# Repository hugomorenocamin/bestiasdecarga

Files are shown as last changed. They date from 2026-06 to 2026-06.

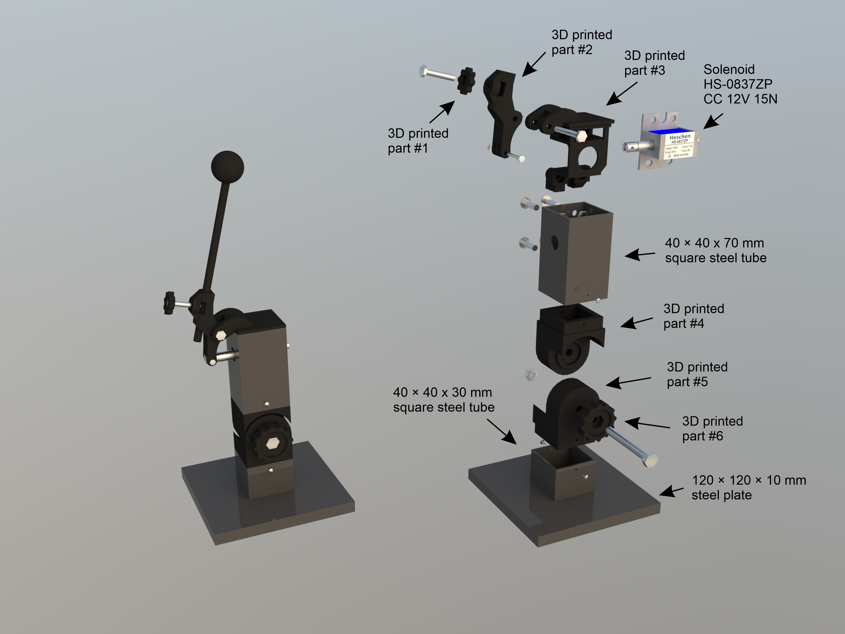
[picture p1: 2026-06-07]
SOLENOID-DRIVEN MALLET/Assembly drawing.jpg

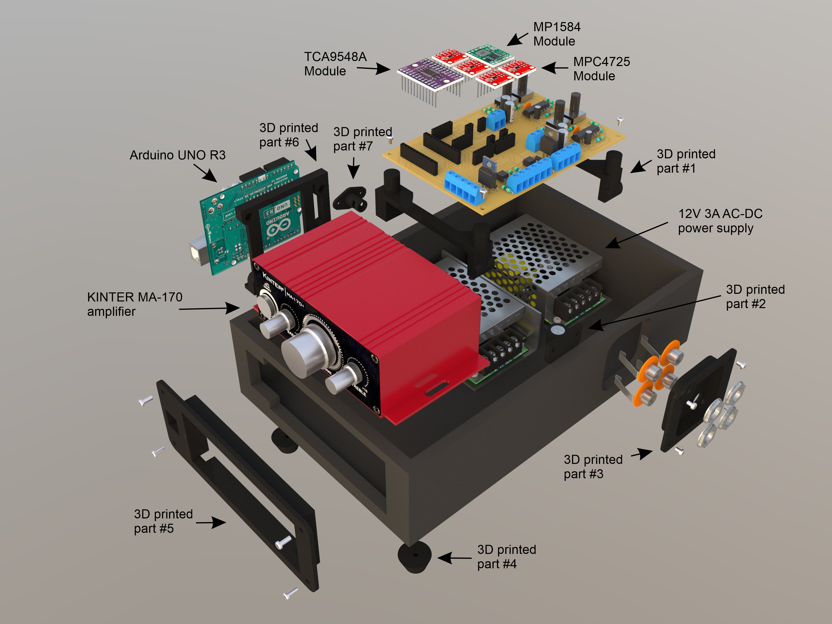
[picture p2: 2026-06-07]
RECEIVER/Assembly 3D drawing2.jpg

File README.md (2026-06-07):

# Bestias de carga
## Overview

This project is an artistic system that sonifies respiratory and cardiac signals in real time.
It operates as a critical reflection on labour, self-exploitation, and the physiological dimension of contemporary neoliberal production regimes.

The body is treated here not as metaphor, but as an operational site of measurement, extraction, and feedback.

The system translates physiological signals into sound, generating a direct physical representation of internal bodily rhythms under stress, attention, and exertion.

## System Structure

### The installation is composed of four interconnected physical modules:

- Part 01 – emitter

- Part 02 – receiver

- Part 03 – respiration belt

- Part 04 – solenoid-driven mallet

### Each module contains:

- Mechanical design and structural drawings

- 3D printable components (.stl)

- Electronics schematics and PCB design

- Firmware (Arduino-based control system)

## Artistic Intent

This work operates at the intersection of bio-sensing and sound art.

It questions:

- the quantification of the body under self-optimization logics

- the feedback loops between attention, labour, and exhaustion

The system is not a medical device, nor a fitness product. It is an artistic instrument.

## Use & Reproduction

This project is released for:

- study and research

- educational use

- artistic reproduction and reinterpretation

- exhibition in cultural, academic and artistic contexts

It is not intended for commercial exploitation.

See ARTISTIC_USE_POLICY.md for detailed terms.

[Artistic Use Policy](ARTISTIC_USE_POLICY.md)

## License

All files in this repository are licensed under:

Creative Commons Attribution-NonCommercial-ShareAlike 4.0 International (CC BY-NC-SA 4.0)

See LICENSE for full terms.

## Author

Hugo Moreno Camín

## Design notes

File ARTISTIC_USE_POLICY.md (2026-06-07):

# Artistic Use Policy

This document clarifies the intended use of this project beyond the legal text of its license.

## Intent

This project is an open artistic system designed for reproduction, study, and reinterpretation within artistic and academic contexts.

It is not intended to function as a commercial product, kit, or manufacturable device.

## Permitted Uses

- Non-commercial reproduction of the system

- Educational and research use

- Artistic modification and derivative works

- Exhibition of derived works in cultural, artistic, and academic contexts

## Not Permitted Without Explicit Permission

- Commercial manufacturing or industrial reproduction of the device

- Sale of assembled units

- Sale of kits or partial kits

- Sale of design files (STL, PCB, schematics, firmware)

- Use of the design as a commercial product or embedded component in a product

## On Derivative Works

Artistic reinterpretations are encouraged.

However, derivative works must:

- Be conceptually and materially distinct from the original system as a device

- Maintain attribution to the original author

- Be released under the same license terms when distributed

## Contact for Artistic Use

If you intend to use any part of this project in an artistic context that involves public exhibition, commissioning, or institutional support, please contact the author in advance to clarify terms and attribution:

Email: hugomoreno311@gmail.com

This allows us to ensure proper attribution and discuss appropriate conditions of use within artistic and curatorial contexts.

## Closing Statement

This project understands the body as a site of measurement, labour, and extraction.

Its openness is intended as a critical gesture, not as a pathway to commodification.

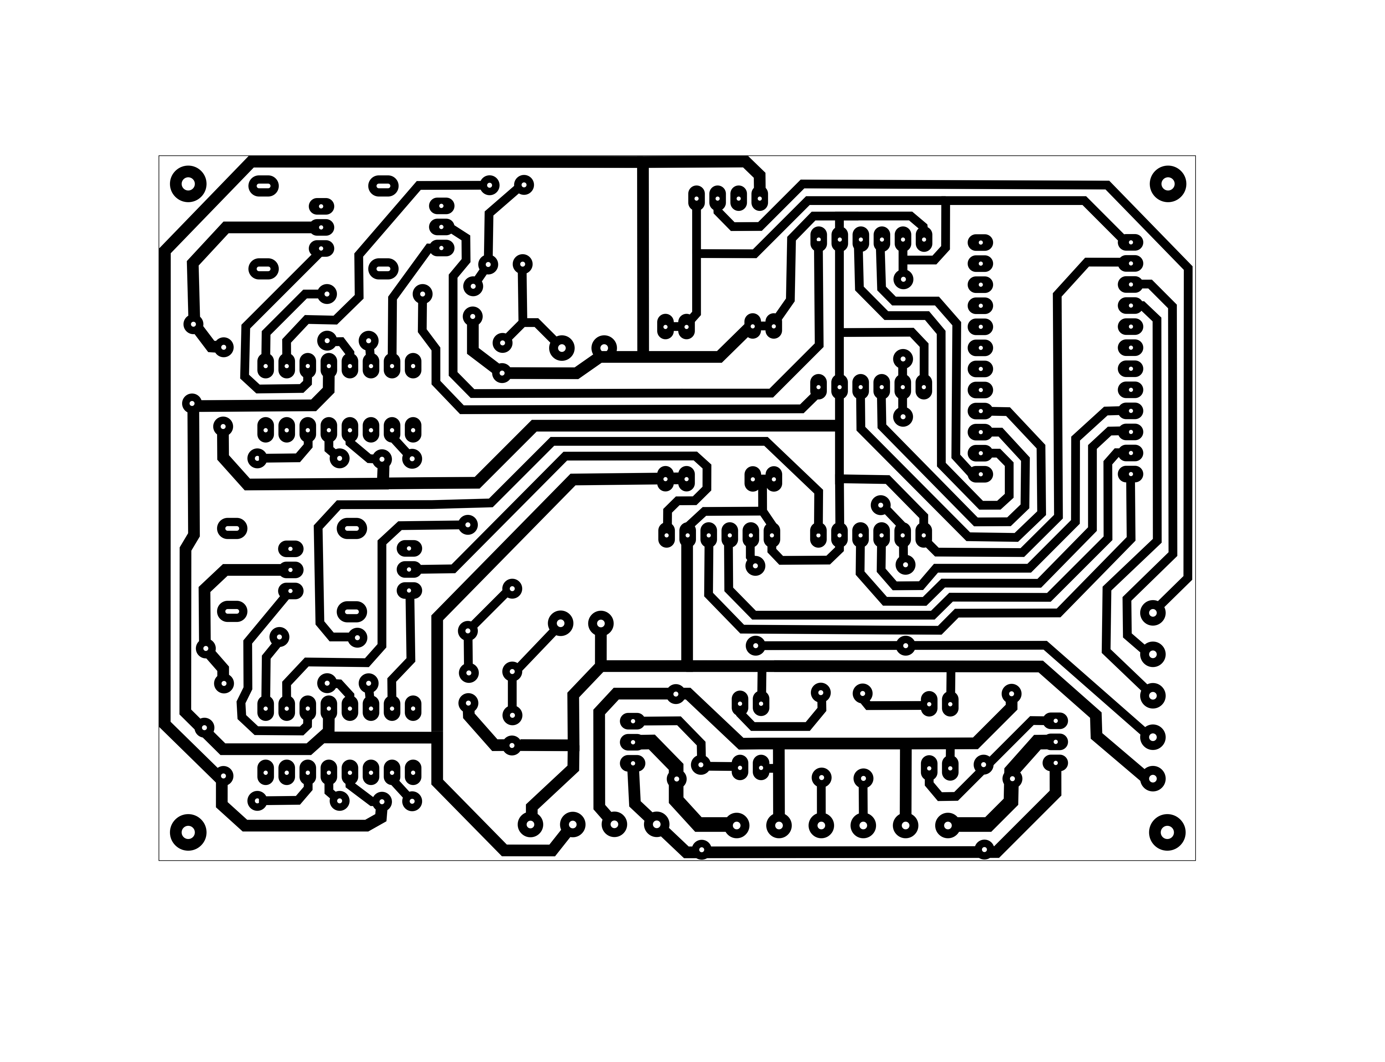
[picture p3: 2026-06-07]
RECEIVER/ELECTRONICS/PCB layout.jpg

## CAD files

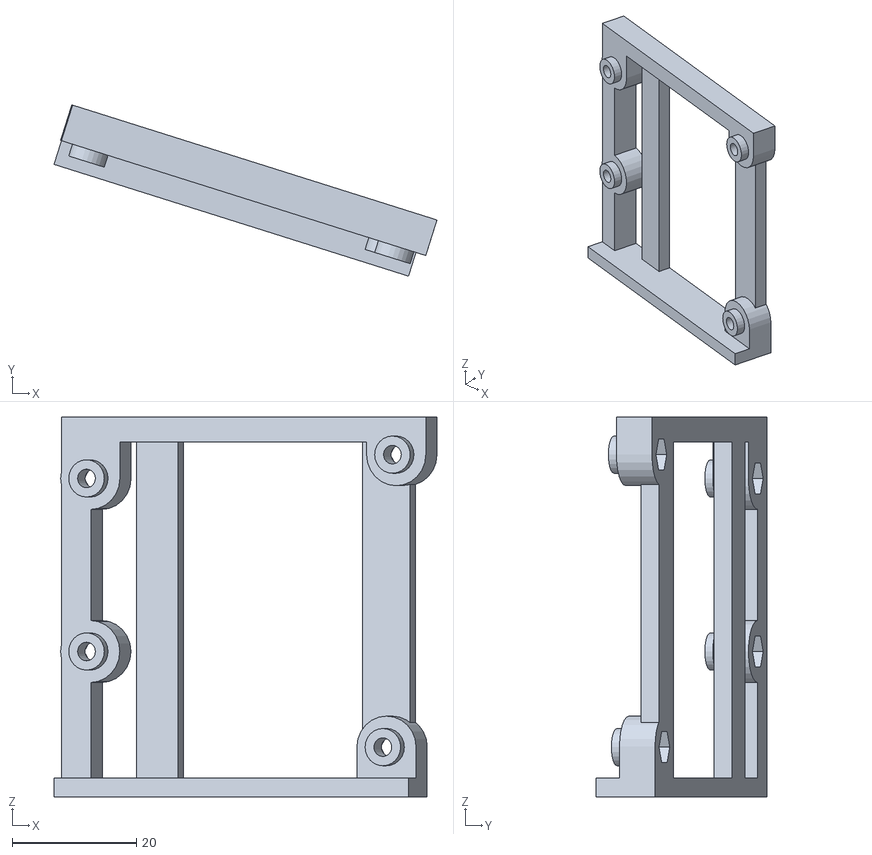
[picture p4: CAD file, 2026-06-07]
RECEIVER/STL/part#6.stl
61.7 x 27.6 x 61.1

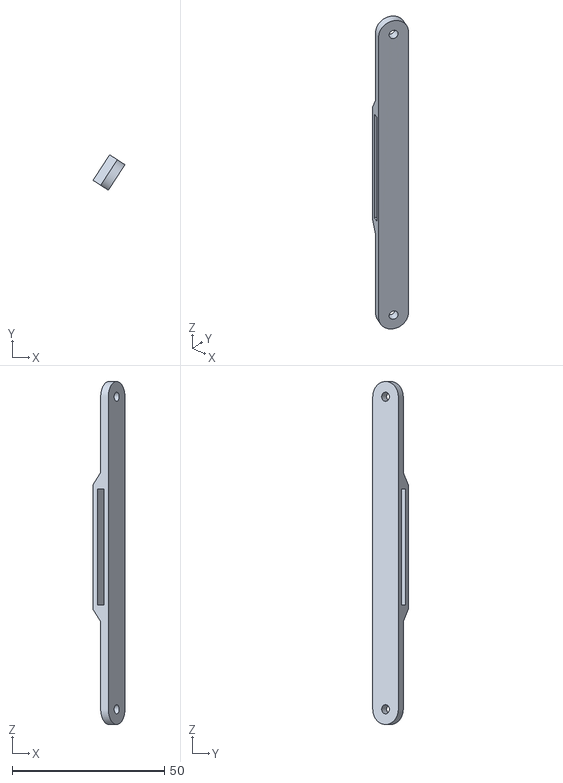
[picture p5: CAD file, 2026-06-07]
RESPIRATION BELT/STL/part#5.stl
10.5 x 11.7 x 112.6

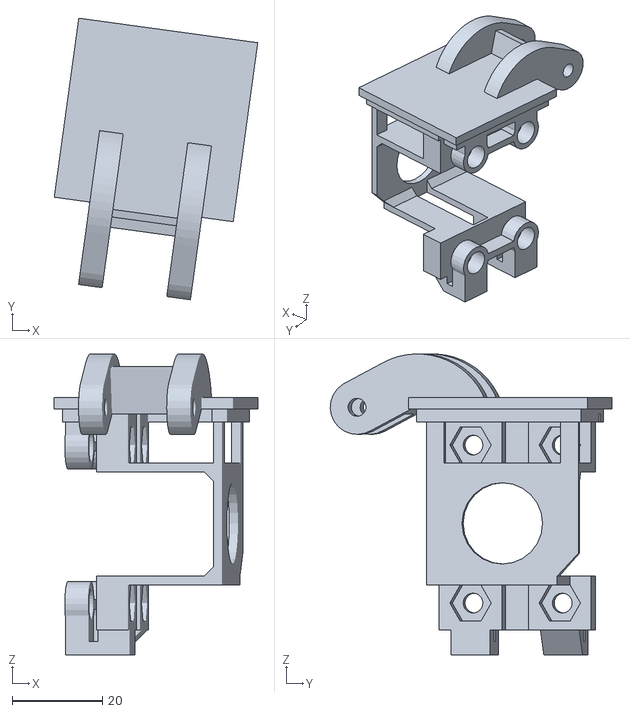
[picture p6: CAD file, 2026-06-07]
SOLENOID-DRIVEN MALLET/STL/part#3.stl
45.1 x 62.3 x 66.6

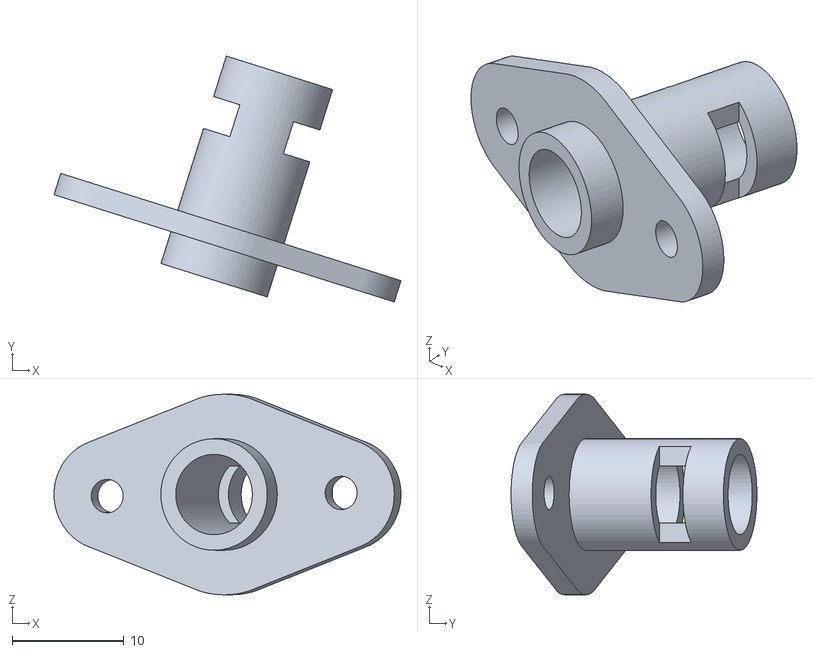
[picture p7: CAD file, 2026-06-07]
RECEIVER/STL/part#7.stl
31.1 x 22.1 x 18.0

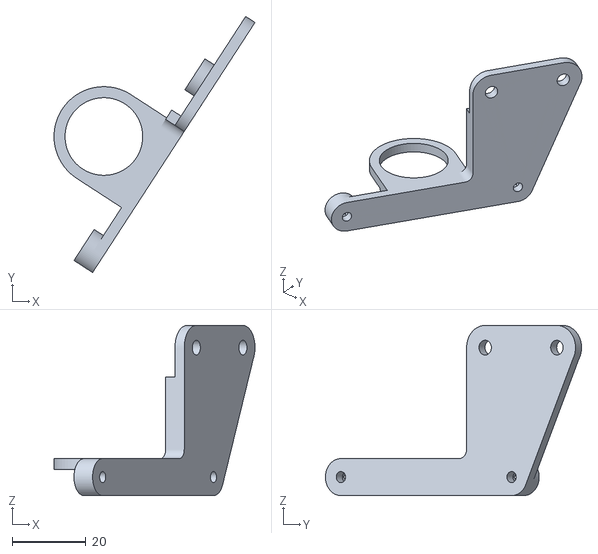
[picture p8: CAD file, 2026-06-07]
RESPIRATION BELT/STL/part#2.stl
54.3 x 69.2 x 46.0

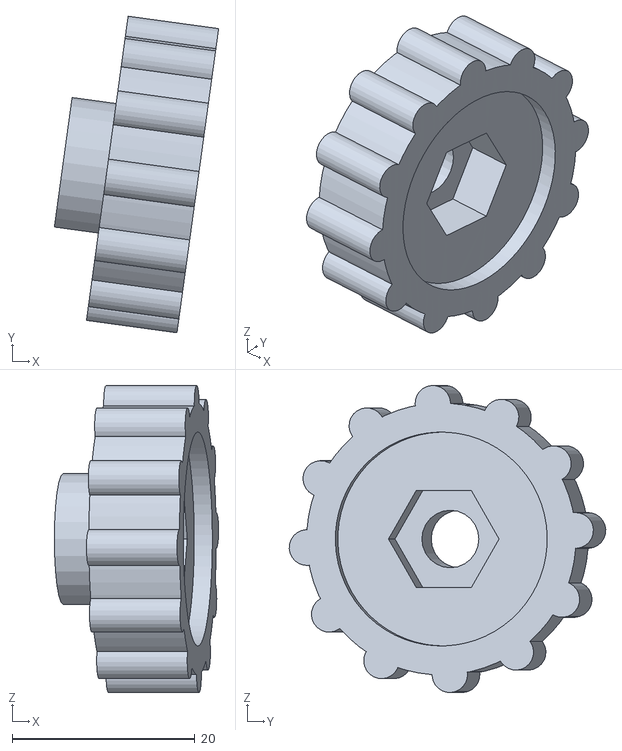
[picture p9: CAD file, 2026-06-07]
SOLENOID-DRIVEN MALLET/STL/part#6.stl
18.0 x 34.6 x 33.6

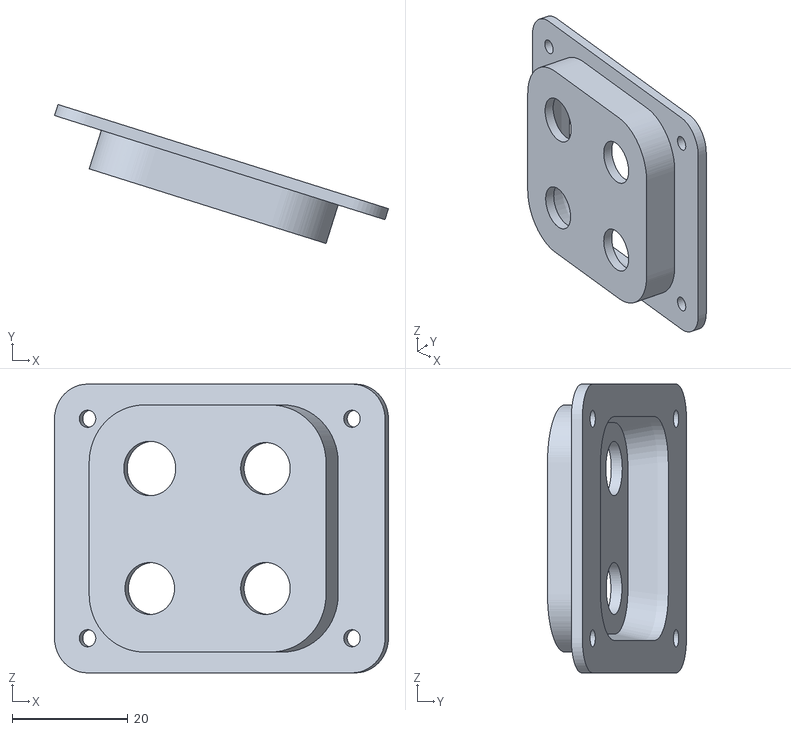
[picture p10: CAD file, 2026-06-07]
RECEIVER/STL/part#3.stl
57.8 x 24.1 x 50.0

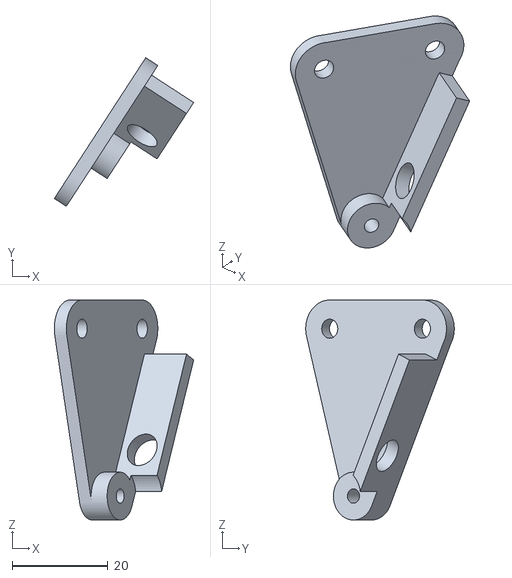
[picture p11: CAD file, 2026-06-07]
RESPIRATION BELT/STL/part#1.stl
29.1 x 31.1 x 46.0

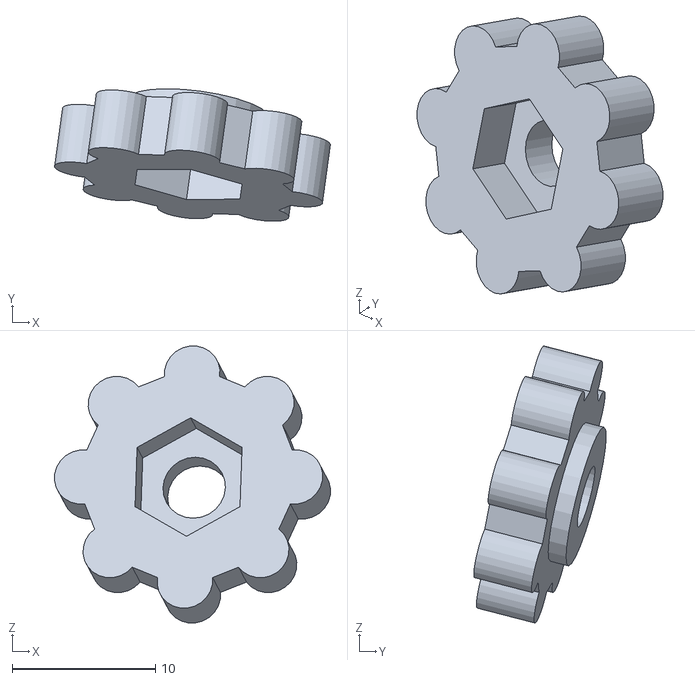
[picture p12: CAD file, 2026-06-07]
SOLENOID-DRIVEN MALLET/STL/part#1.stl
19.3 x 9.25 x 19.3

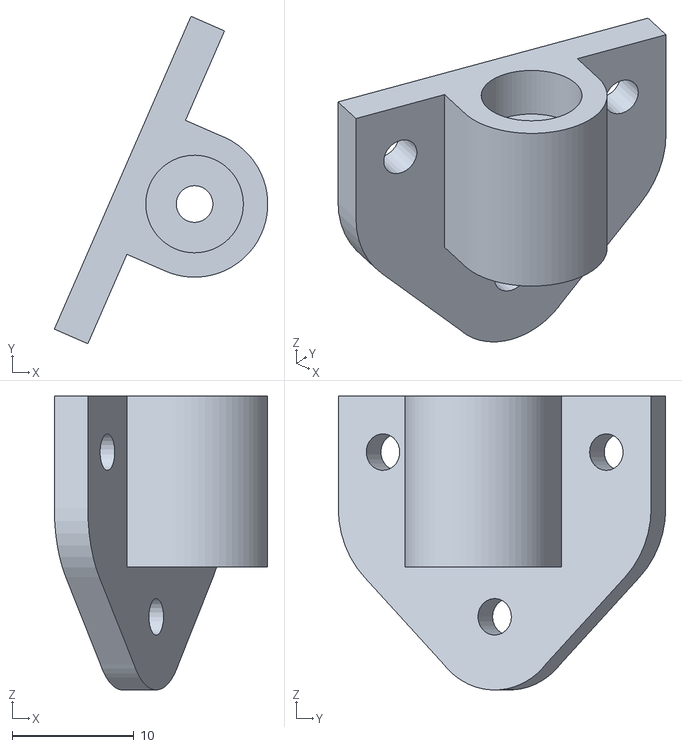
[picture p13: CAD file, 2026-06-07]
RECEIVER/STL/part#2.stl
17.5 x 26.8 x 24.1

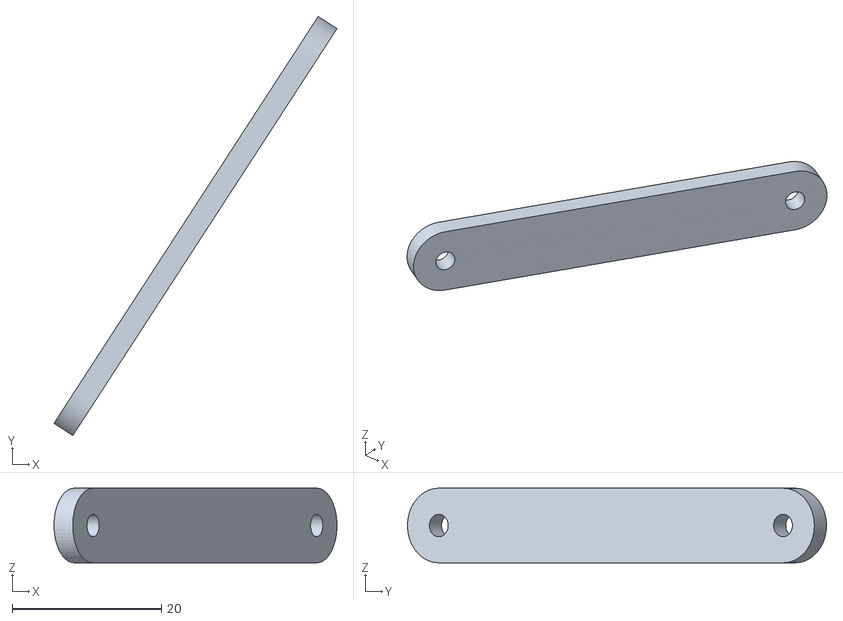
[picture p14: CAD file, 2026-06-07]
RESPIRATION BELT/STL/part#4.stl
37.9 x 56.1 x 10.0

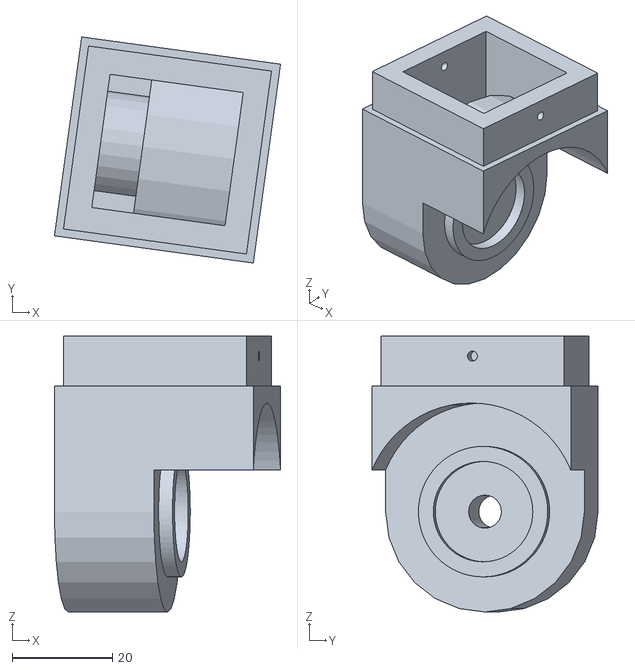
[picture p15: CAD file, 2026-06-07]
SOLENOID-DRIVEN MALLET/STL/part#4.stl
45.1 x 45.1 x 55.0

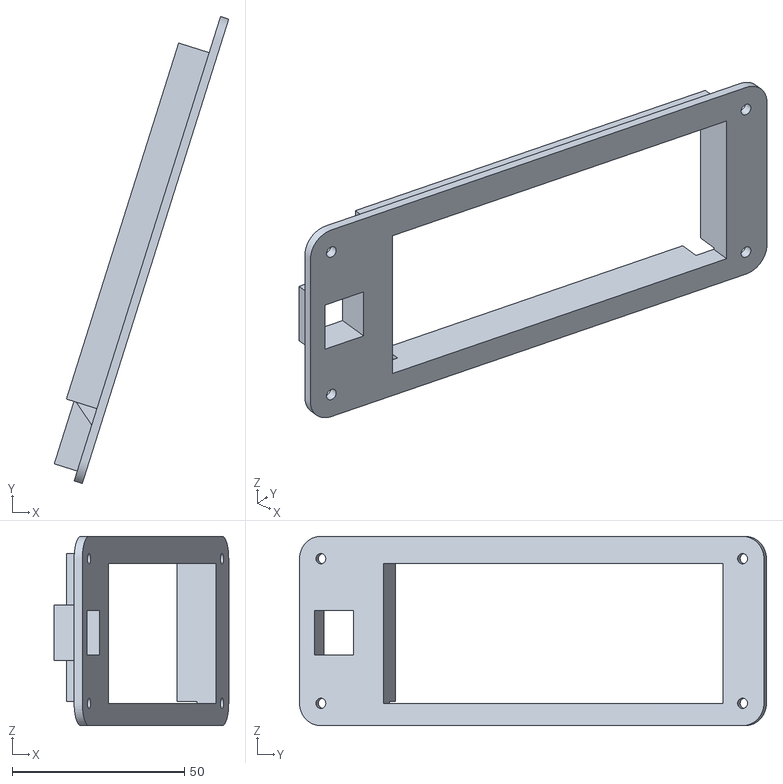
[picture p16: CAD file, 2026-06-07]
RECEIVER/STL/part#5.stl
50.7 x 135.6 x 55.0

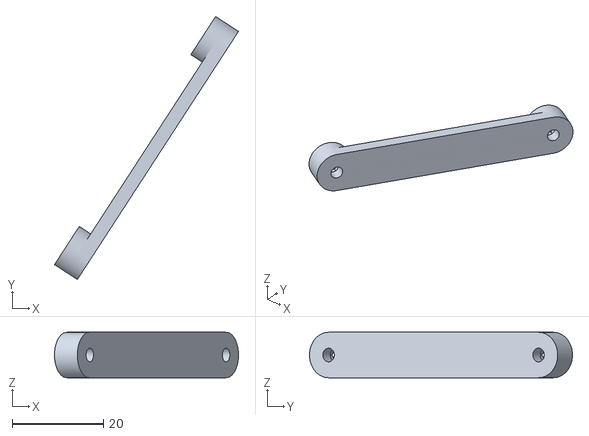
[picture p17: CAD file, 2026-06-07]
RESPIRATION BELT/STL/part#3.stl
40.4 x 57.8 x 10.0

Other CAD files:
SOLENOID-DRIVEN MALLET/STL/part#5.stl
RECEIVER/STL/part#1.stl
SOLENOID-DRIVEN MALLET/STL/part#2.stl
RECEIVER/STL/part#4.stl
EMITTER/STL/part#1.stl
EMITTER/STL/part#2.stl
EMITTER/STL/part#3.stl

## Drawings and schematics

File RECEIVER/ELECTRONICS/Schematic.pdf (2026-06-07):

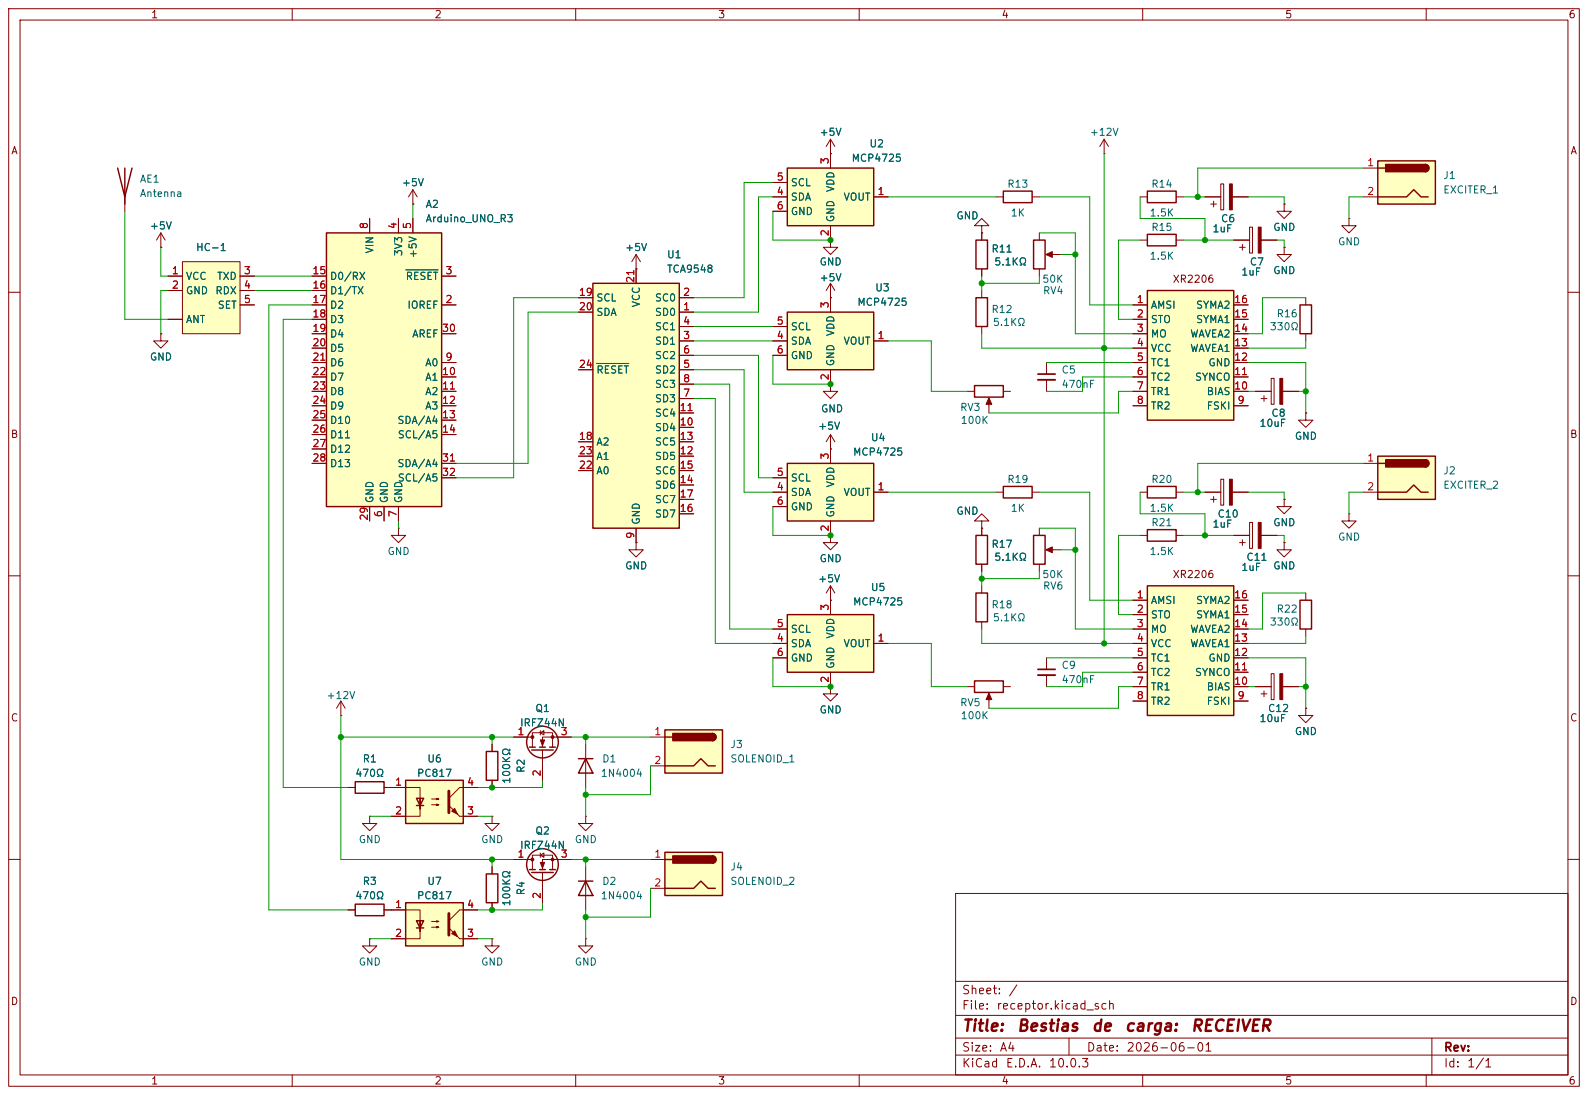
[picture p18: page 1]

TC2 6
TR1 7

Sheet: /
File: receptor.kicad_sch
Title: Bestias de carga: RECEIVER

Size: A4 | Rev:
KiCad E.D.A. 10.0.3 | Id: 1/1

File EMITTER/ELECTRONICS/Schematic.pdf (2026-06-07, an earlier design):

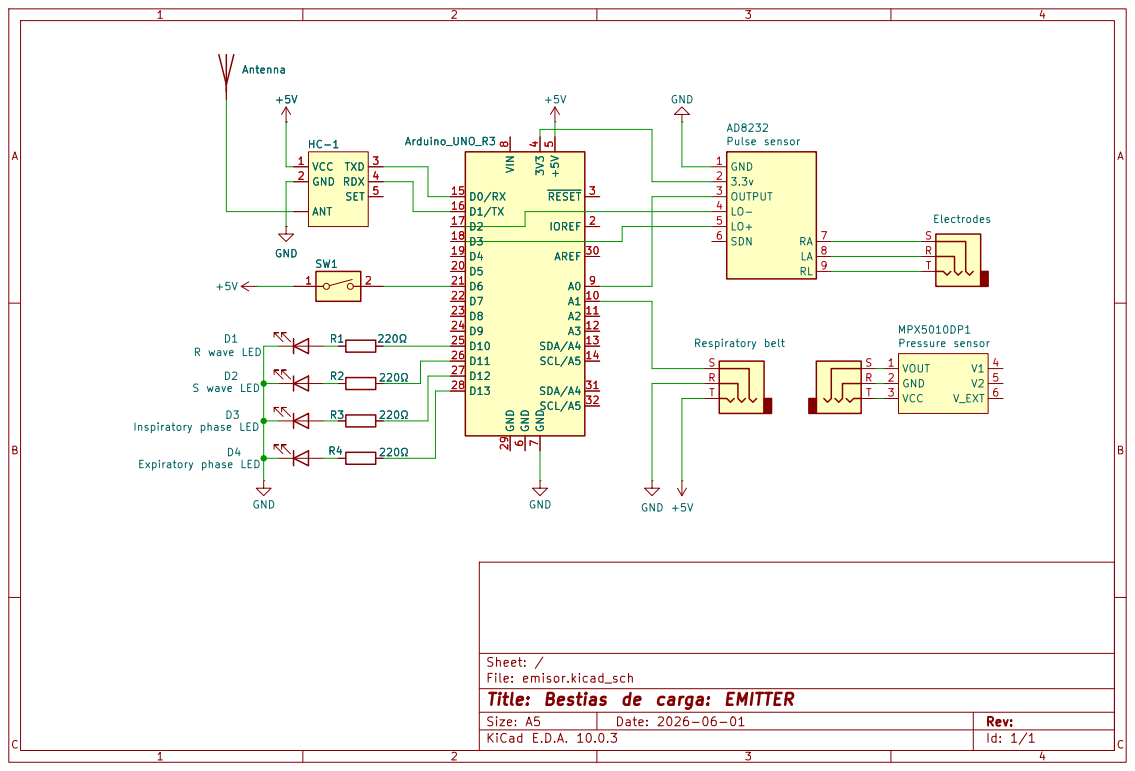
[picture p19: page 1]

Sheet: /
File: emisor.kicad_sch
Title: Bestias de carga: EMITTER

Size: A5 | Date: 2026-06-01 | Rev:
KiCad E.D.A. 10.0.3 | | Id: 1/1

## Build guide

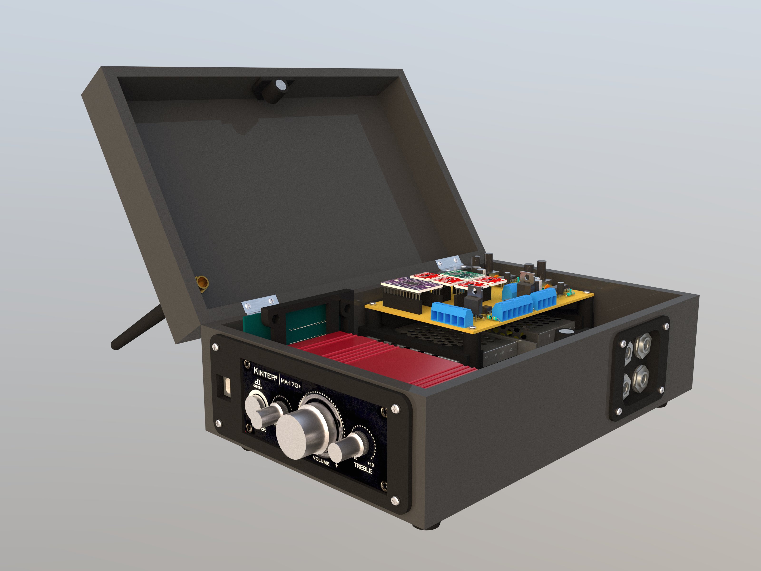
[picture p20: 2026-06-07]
RECEIVER/Assembly 3D drawing1.jpg

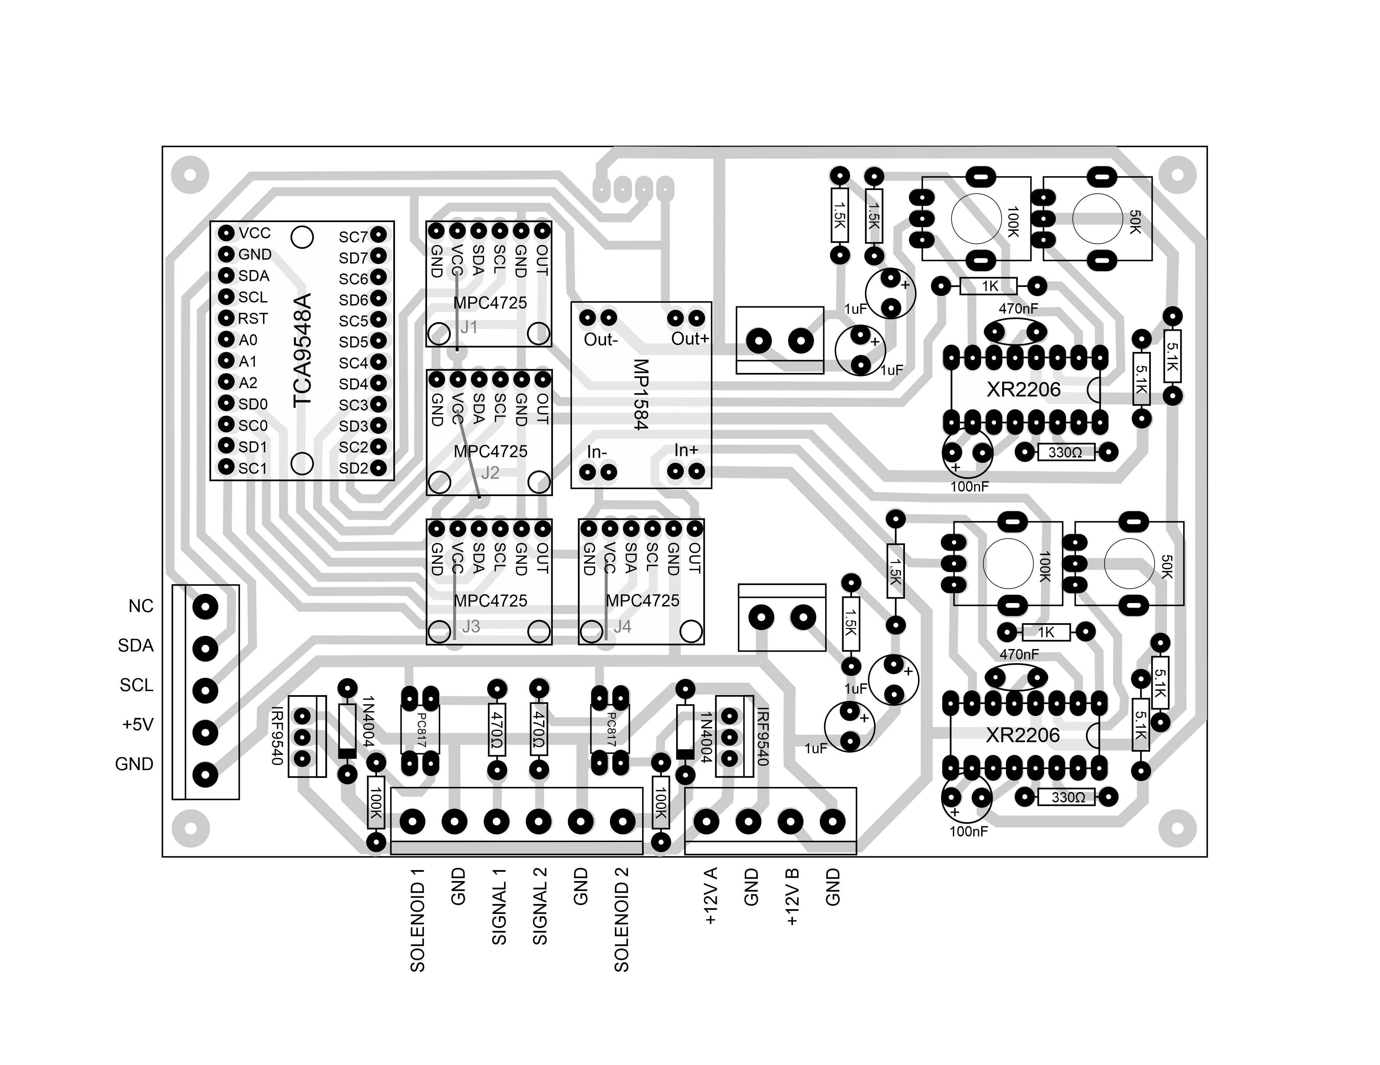
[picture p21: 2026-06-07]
RECEIVER/ELECTRONICS/Assembly drawing.jpg

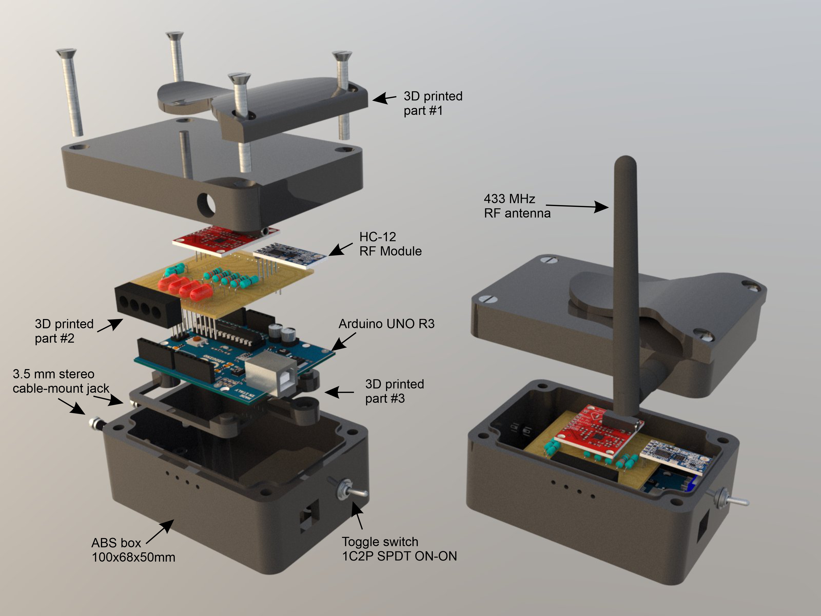
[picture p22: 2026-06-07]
EMITTER/Assembly 3d drawing.jpg

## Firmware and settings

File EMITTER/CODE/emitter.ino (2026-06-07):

#include <Filters.h>

#include <AH/Timing/MillisMicrosTimer.hpp>
#include <Filters/Butterworth.hpp>

auto filter = butter<2>(.01);
auto filter2 = butter<2>(.14);

int Rtrig;
char Rstr[5];


const int ecgPin = A0;
const int respPin = A1;

// Buffer para filtro de 5 muestras ECG
float x0 = 0, x1 = 0, x2 = 0, x3 = 0, x4 = 0;

float filtered = 0; //señal filtrada ECG
float filteredy = 0; //señal filtrada RESP

// Derivada ECG
float prevFiltered = 0;
float slope = 0;

// Derivada RESP
float prevFilteredy = 0;
float slopey = 0.0;
float respp=0;

// Umbrales ECG
float slopeThresholdR = 15;   // pendiente fuerte (R)
float slopeThresholdT = 3;    // pendiente más suave (T)

unsigned long currentTime = 0;
unsigned long dt = 0;
unsigned long lastRTime = 0;
unsigned long lastTTime = 0;

bool detectedR = false;
bool detectedT = false;

int maza1=0;
int maza2=0;
int R=0;
int T=0;

int exciter1=0;
int exciter2=0;
float bandamax=500;
float bandamin=200;


void setup() {
  Serial.begin(38400);
  pinMode(2, INPUT); // Setup for leads off detection LO +
  pinMode(3, INPUT); // Setup for leads off detection LO -
  pinMode(6, INPUT_PULLUP); // interruptor RF
  pinMode(10, OUTPUT); // Setup for led resp up
  pinMode(11, OUTPUT); // Setup for led resp down
  pinMode(12, OUTPUT); // Setup for led maza1
  pinMode(13, OUTPUT); // Setup for led maza2

}

void loop() {
  
  currentTime = millis();
  
//////////    procesa ECG   /////////
  if((digitalRead(2) == 0) && (digitalRead(3) == 0))
  {
  // Leer nueva muestra
 
  // --- FILTRO BUTTERW DE 35Hz/250Hz->0.14 ---
  filtered = filter2(analogRead(ecgPin));
  
  // --- DERIVADA (pendiente) ---
  slope = filtered - prevFiltered;

  // --- DETECCIÓN DE ONDA R ---
  // busco subida rápida (pendiente positiva grande)
  if (slope > slopeThresholdR && detectedR==false) {
    lastRTime = currentTime;
    detectedR = true;      
    maza1=1;
    digitalWrite(12,HIGH);   
  }

  if(detectedR  && (currentTime-lastRTime)>100) //apago maza1 pasados 100ms
  {
        maza1=0;   
        digitalWrite(12,LOW);         
  }

  // --- DETECCIÓN DE ONDA T ---
  if (detectedR ) {
    dt = currentTime - lastRTime;

    // ventana fisiológica típica
    if (dt > 150 && dt < 400 &&  detectedT == false) {
      if (slope > slopeThresholdT) {
         
         detectedT = true;
         lastTTime = currentTime;
         maza2=1;
         digitalWrite(13,HIGH);       
       }
    }
  }
 
    if(detectedT==true && (currentTime-lastTTime) >100) //apago maza2
    {
      maza2=0;
      digitalWrite(13,LOW);
      detectedT=false;
      detectedR = false;
    }

    // reset de seguridad
    if (dt > 500) {
      detectedR = false;
      detectedT = false;
      maza1=0;
      maza2=0;  

    }
  
  prevFiltered = filtered;
  }

  else{
   ;
  }
  /////////////////// fin ECG  ///////////////

 
  ////////////detecto respiracion //////////

  // --- FILTRO BUTTERW DE 2.5Hz/250Hz->0.01 ---
  filteredy=filter(analogRead(respPin));
  // --- DERIVADA (pendiente) ---
  slopey =  filteredy-prevFilteredy;

 
  if (slopey>.2){exciter1=1;analogWrite(10, 10);}
  if (slopey<-0.2){exciter2=1;analogWrite(11, 10);}
  if (slopey>=-0.2 && slopey<=0.2){exciter1=0; exciter2=0;}

  if(exciter1==0){analogWrite(10, 0);}
  if(exciter2==0){analogWrite(11, 0);}

  prevFilteredy = filteredy;

  delay(5); // ~250 Hz

  //valor en % de respiracion
  respp= mapf(filteredy,bandamin,bandamax,0.0,100.0);
  if (respp<0.0){respp=0.0;}
  if (respp>100.0){respp=100.0;}

  if(digitalRead(6) == 1)
    {

    Serial.print(maza1);
    Serial.print(" ");
    Serial.print(maza2);
    Serial.print(" "); 
    Serial.print(exciter1);
    Serial.print(" ");
    Serial.print(exciter2);
    Serial.print(" ");
    Serial.println(slopey*1000);

  }      
      
}

float mapf(float x,float in_min,float in_max,float out_min,float out_max) 
{
  return (x - in_min) * (out_max - out_min) / (in_max - in_min) + out_min;
}

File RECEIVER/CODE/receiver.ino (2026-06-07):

#include <Wire.h>

#define TCA_ADDR 0x70   // Dirección del TCA9548A
#define  MCP_ADDR 0x60  // Dirección del DAC

int b1 = 0; //maza 1
int b2 = 0;  //maza2
int b3 = 0;  //exciter1
int b4 = 0;  //exciter2
float v1 = 0; //valor resp 0-100
String data = "";

// Seleccionar canal del TCA9548A
void tcaSelect(uint8_t i) {
  if (i > 7) return;
  Wire.beginTransmission(TCA_ADDR);
  Wire.write(1 << i);  // Activa canal i
  Wire.endTransmission();
}

void writeDAC(uint16_t value) {
  Wire.beginTransmission(MCP_ADDR);
  // Comando rápido para MCP4725
  Wire.write(0x40);  // Write DAC register
  Wire.write(value >> 4);        // 8 bits altos
  Wire.write((value & 0xF) << 4); // 4 bits bajos
  Wire.endTransmission();
}

void setup() {

   Serial.begin(38400);
   delay(1000);
   Wire.begin();
   
  pinMode(2, OUTPUT); // Setup for maza1
  pinMode(3, OUTPUT); // Setup for maza2

}


void loop() {
  while (Serial.available()) 
  {

  char c = Serial.read();
  
    if (c == '\n') {

      // Parsear
      int valores[5];

      int index = 0;
      char buffer[50];
      data.toCharArray(buffer, 50);

      char *token = strtok(buffer, " ");

      while (token != NULL && index < 5) {
        valores[index++] = atoi(token);
        token = strtok(NULL, " ");
      }
         
      b1 = valores[0];
      b2 = valores[1];
      b3 = valores[2];
      b4 = valores[3];
      if(valores[4] <0){v1 = -valores[4];}
      if(valores[4] >=0){v1 = valores[4];}    
      data = "";
    }
    else {
      data += c;
    }
  }

//// MAZAS
if (b1==1){digitalWrite(2,HIGH);}
if (b1==0){digitalWrite(2,LOW);}
if (b2==1){digitalWrite(3,HIGH);}
if (b2==0){digitalWrite(3,LOW);}

//// EXCITERS
if (b3==1){tcaSelect(2);writeDAC(10);} //freq}
if (b3==0){tcaSelect(2);writeDAC(3600);}
if (b4==1){tcaSelect(1);writeDAC(10);}
if (b4==0){tcaSelect(1);writeDAC(3600);}

int amplitud=map(int(v1), 0, 2000, 3400, 0); //valor mapeado a DAC 0=3600

if(amplitud>3400){amplitud=3400;}
if(amplitud<0){amplitud=0;}

tcaSelect(0);writeDAC(amplitud);
tcaSelect(3);writeDAC(amplitud);

delay(3);
      
}
